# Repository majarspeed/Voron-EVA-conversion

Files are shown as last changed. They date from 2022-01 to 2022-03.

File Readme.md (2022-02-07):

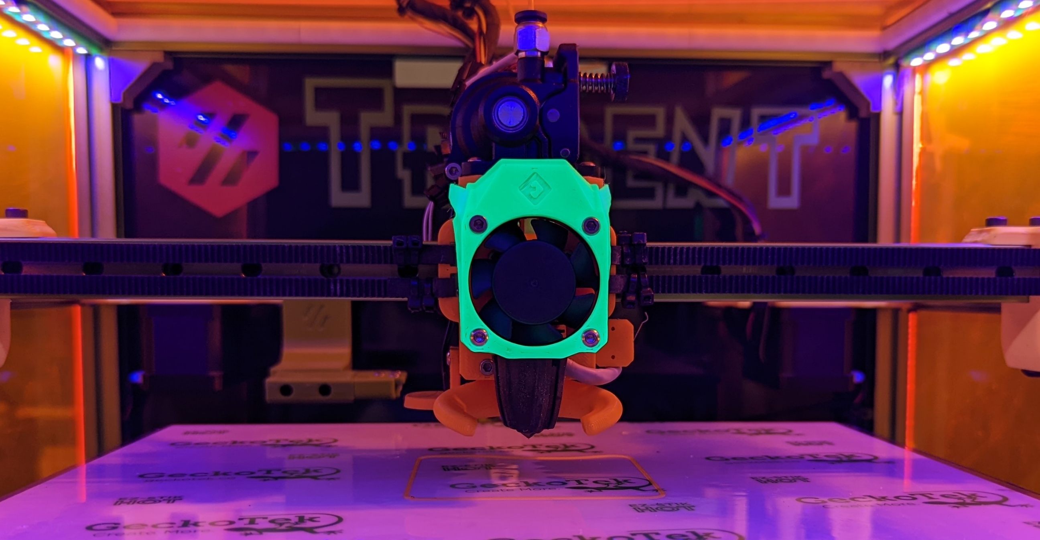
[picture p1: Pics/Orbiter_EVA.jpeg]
Orbiter EVA on Voron

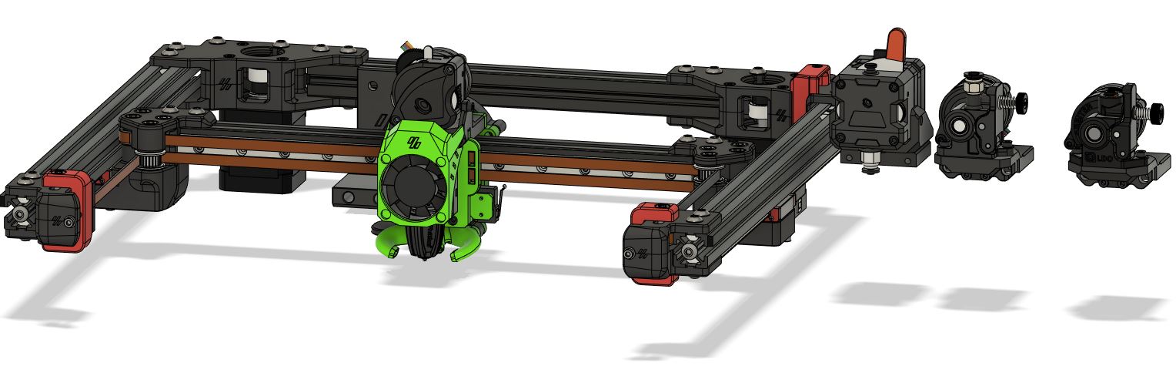
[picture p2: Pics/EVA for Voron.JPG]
fusion EVA on Voron


This is a repository for the CAD and STL for the EVA to Voron conversion. 

This is not an original work. All of this is the work of the EVA team and Voron Design. I only made minor modifications to allow the use of the excellent EVA hotend system. Please visit EVA at https://main.eva-3d.page/ and Voron Design https://vorondesign.com/ and consider suppoting both of these worthy projects. 

The goal was to make as little change to either system as possible. So primarily I wanted to not have to redesign the belt pathing on the Voron or relocate the rail. And to minimize the changes to the EVA and retain as much as I could of the EVA compatibility. 

Primarily what this means is I added heat sets to the top of some mounts and added a spacer/endstop with mounting holes for the faceplate to the MGN12. 
Homing does need to be modified to work with this modification. I am using Homing override to ensure that I home x and they move to a location away from the corner before I home the y axis.

# Update 2 

Added some addtional spacing on the housing. Some was just a little to close. 
Added ad spacer using a df2 microswitch. 
Added sherpa mini top. 

Began testing of a MGN 9 variant. 

Some have asked for a weight comparsion. Weighed a EVA with Sherpa top all parts except hotend and extruder. 124 grams 

# UPDATE 1 Voron EVA conversion gets better Klicky
I have created a klicky duct that is based off of Whooppingpochard from the Voron discords design. And adapted it to the trihorn ducts. This is a much easier method and allows the use of the stock klicky and auto z configuration. This makes this a much easier conversion overall. Will retain the previous instructions in the klicky readme if you would still prefer to use this with that configuration. 

Also adding a user mod for some user based alternative parts. 
Adding a clamp style multipart uface desigh thanks to DoubleT ont he Voron Discord. 

# READ FIRST: THIS IS A CHALLENGING MOD. 
*"This mod may require significant individualization. Evaluate your own build and select your parts as needed." --Corvidbuild V2
This is an excellent description.*

I have a mix of modified parts and unmodified parts. 
Primarily you will need the modified Universal face and modified corexy back. The modified face has 4 holes to mount to the mgn 12 and 2 holes for heat sets to mount the hotend adapters. The modified universal plate should work with all popular hot end mounts these are un-modified (please visit the EVA site to get the files mount to fit your particular hot end.)I initially had the belts clamped with the mgn12 while effective you need 5 arms to get it lined up correctly. So I have added loops and secure the belts with zip ties.

The bottom is modified with heat sets for custom side mounted klicky mount if wanted.

The tops for several extruders are modified to work with this. LGX and LGX lite modified top as well as Orbiter 1.5/2.0 modified top and BMG modified top are included in the files. 

The x end stop is located on the carriage and is integrated with a new part I created called universal spacer.

I have a thinner versions of the rear universal wire mount.

All screw sizes are the same as stock with the exception of the through screws which need at least 5 extra mm to reach.

## THIS IS A CHALLENGING conversion please do not take this lightly.

# Configuration Changes

## Homing 
Below is an example of my homing changes to ensure I do not hit the AB motor mounts. 

```
[homing_override]
axes: z
set_position_z: 0
gcode:
   G90
   G0 Z5 F600
   G28 X
   ## Set X below to a sale location off of the right corner to ensure that you do not hit the AB mount when HOMING. 
   G0 X225 F7200
   G28 Y
   ##	XY Location of the Z Endstop Switch
   ##	Update X0 and Y0 to your values (such as X157, Y305) after going through
   ##	Z Endstop Pin Location Definition step.
   G0 X163.00 Y295 F3600 
   G28 Z
   G0 Z10 F1800
   ##Park after Homing
   G0 X163 Y260 Z30 F7200 
   ```

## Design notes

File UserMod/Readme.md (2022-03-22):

Added alternative klicky mount for Volcano/UFH nozzles. 
Added Orbiter 2.0 Hartk mount 
Addied Umbilical mount for frame.

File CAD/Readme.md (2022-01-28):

Location for all CAD for the EVA conversion.

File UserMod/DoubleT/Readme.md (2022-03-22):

Multipart Universal face for Voron EVA conversion. Contributed by DoubleT from the Voron Discord. 

3/22/22 
Added alternative klicky mount for Volcano/UFH nozzles.
Added Orbiter 2.0 Hartk mount 
Addied Umbilical mount for frame.

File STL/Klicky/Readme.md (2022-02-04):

The new duct based mount is a simpler and easier to implement solution. You just need to print the slightly longer arm mount or use the variable height arm from the Klicky mod repo. And fllow the standard setup for klicky mod. 

I also added a thicker klicky side mount and moved the directions for this here in case you still wish to utilize it. 

# Side mount Klicky needed changes.
## Probe

### Probe offset 
```
x_offset: -24
y_offset: 30
```
### Mesh max 
Needs to be shrunk as it looks at the nozzle location not the offset. 
```
mesh_max: 250,260 
```
## Z-tilt
And the Z-tilt will need to be adjusted for your particular bed. My bed is not a standard so would not be helpful. Just keep in mind that the probe offset is not used when setting these. 
# Auto-z
This I am looking to improve 
But currently this is the changes I used to make this work in my configuration. 
These are the ADDTIONAL besides the normal changes to configure auto z. 
The below are found in the klicky-probe-for_VT.cfg on my configuration. 
### Probe Entry 
The below needs to be modified to change where it starts the dock and undock from. 

```
# Probe entry location
        #set the below location to 20 mm to the right of the dock location. 
         G0 X 143 Y 275 F3600
        #G0 X{Dx|int - Ax|int} Y{Dy|int - Ay|int} F{St}
        #{% if Dz != -128 %}
        #    G0 Z{Dz|int - Az|int} F{Sd}
        #{% endif %}
```

### Dock move
Below needs to be added:
```
#dock move
Variable_dockmove_x:             0
Variable_dockmove_y:           -40
Variable_dockmove_z:             0

#attach move
Variable_attachmove_x:         -40
Variable_attachmove_y:           0
Variable_attachmove_z:           0
```

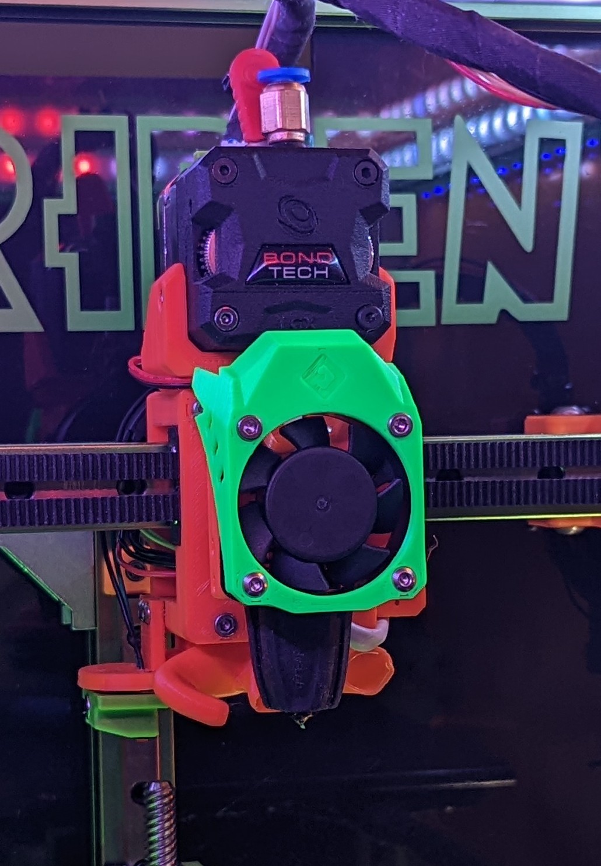
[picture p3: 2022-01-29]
Pics/LGX_EVA.jpeg

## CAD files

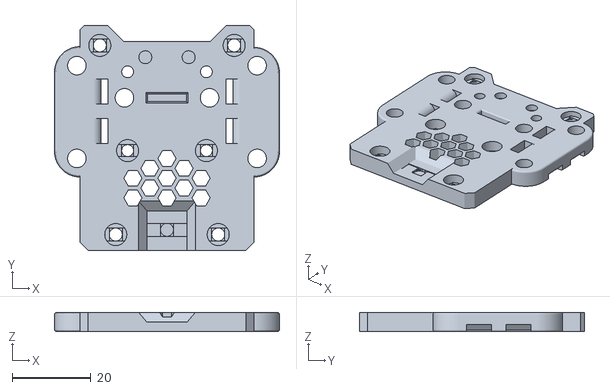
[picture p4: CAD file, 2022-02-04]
UserMod/DoubleT/Voron_U-face_mpart_main.stl
57.1 x 57.0 x 4.90

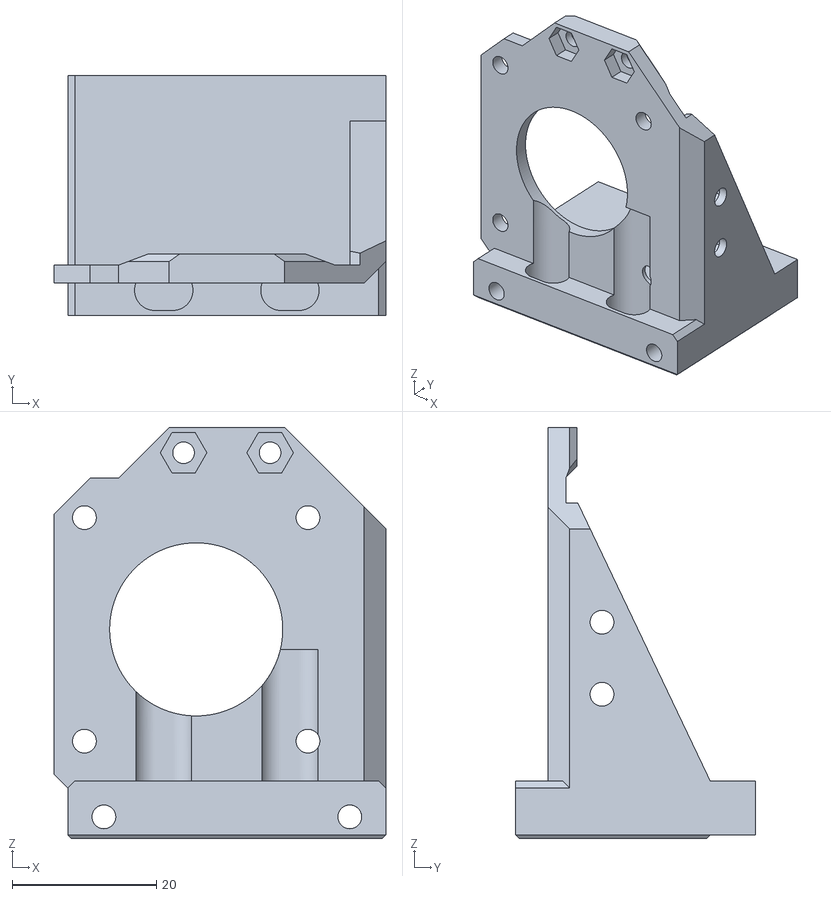
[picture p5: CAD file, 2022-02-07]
STL/BMG/top_bmg_mgn12.stl
46.0 x 33.3 x 57.0

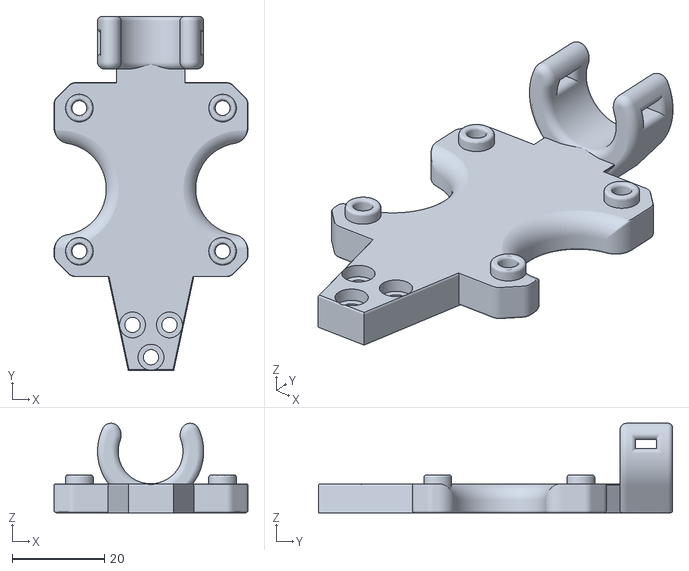
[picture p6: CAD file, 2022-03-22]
STL/huvud_eva_oriented.stl
42.0 x 76.7 x 19.4

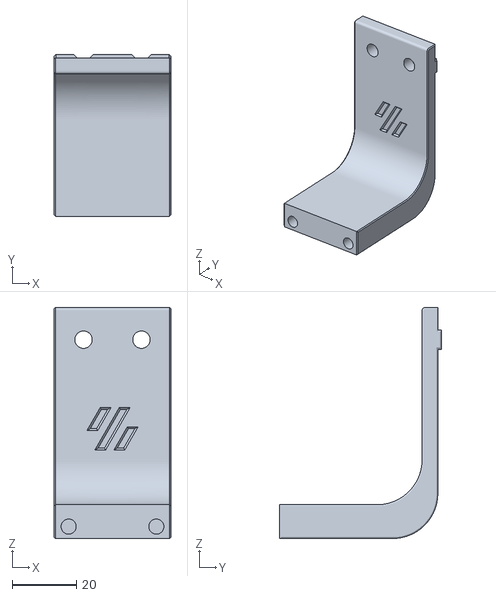
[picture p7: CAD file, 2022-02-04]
STL/Klicky/Duct height arm EVA.stl
36.3 x 50.3 x 71.8

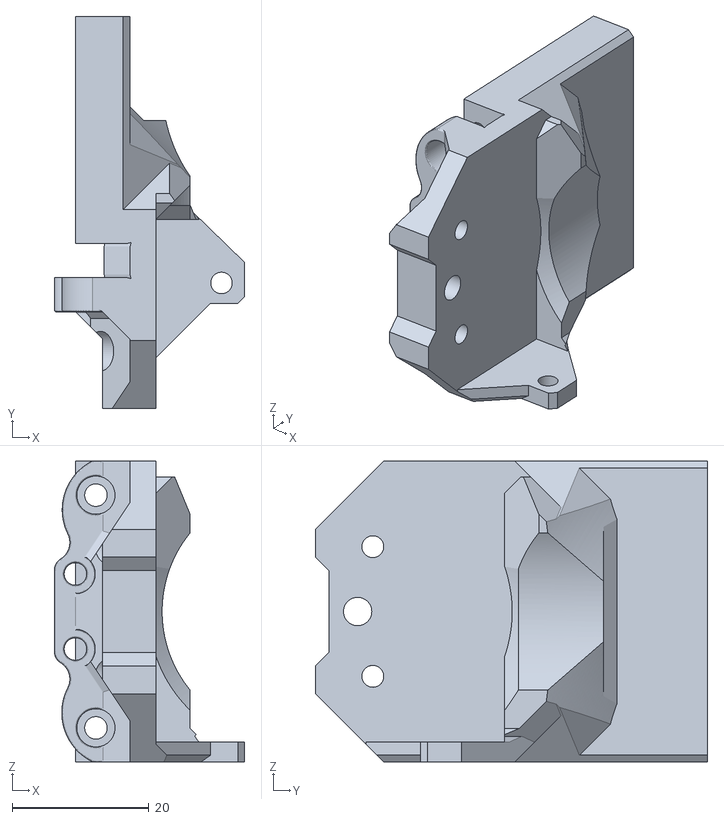
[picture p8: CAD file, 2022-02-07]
STL/LGX/top_mgn12_LGXM.stl
27.9 x 57.5 x 44.1

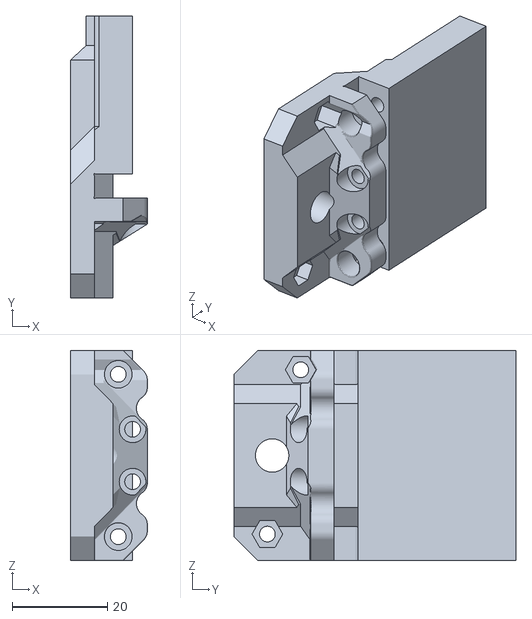
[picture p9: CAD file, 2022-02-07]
STL/orbiter/top_orbiter_1_5_mgn12.stl
16.1 x 59.2 x 44.1

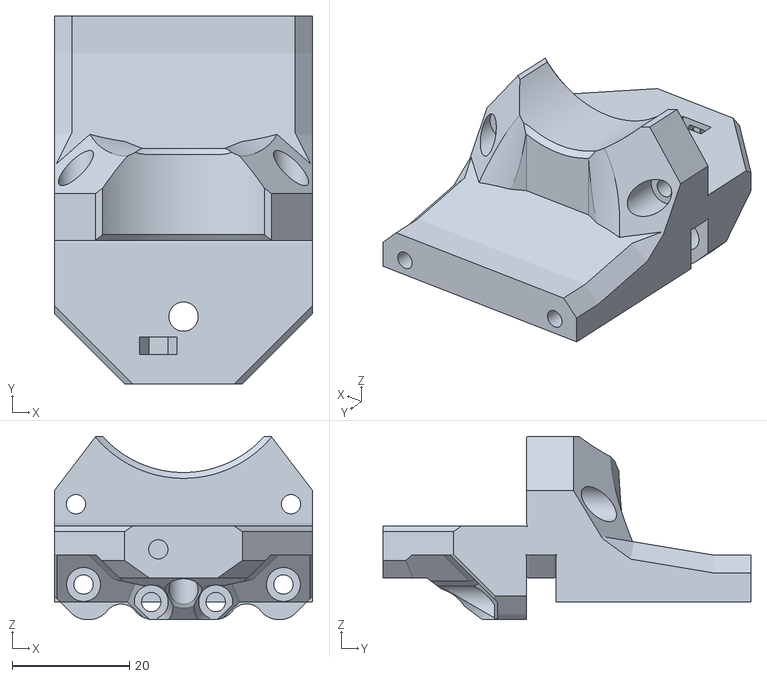
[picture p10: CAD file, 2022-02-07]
STL/Sherpa/top_sherpa_mgn12.stl
44.1 x 62.8 x 31.3

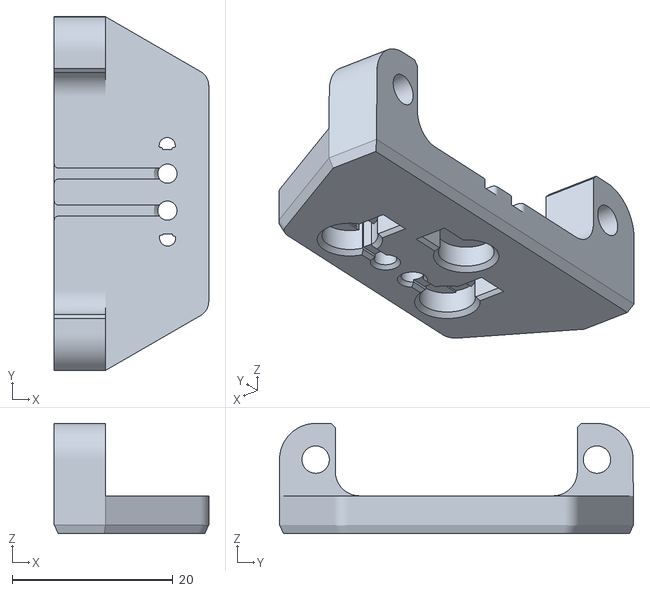
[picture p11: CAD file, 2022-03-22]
UserMod/DoubleT/Eva Mount dt klicky mount.stl
19.2 x 44.0 x 13.7

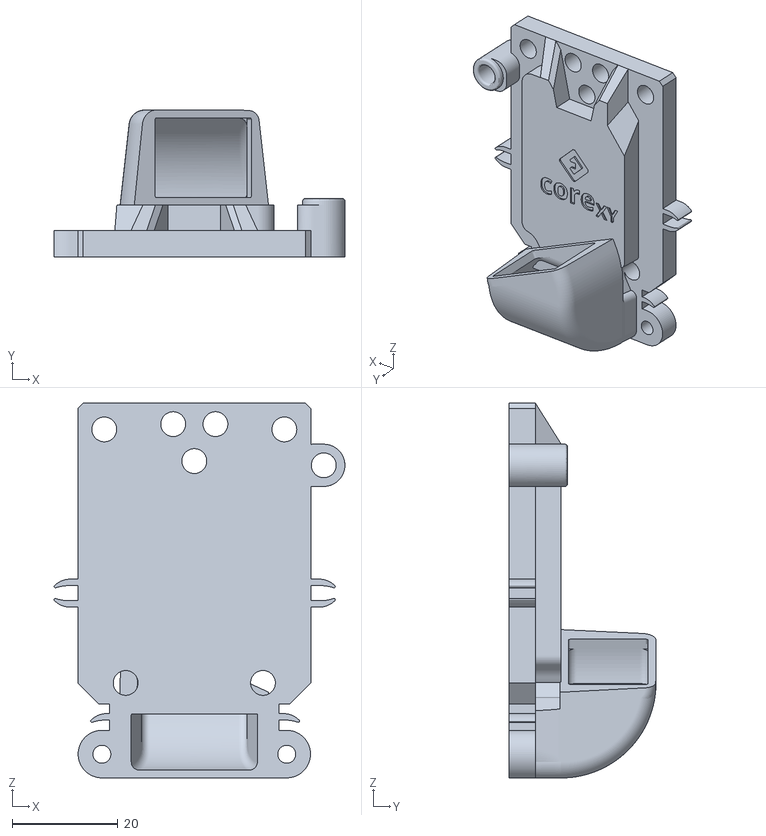
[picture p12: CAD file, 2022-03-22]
STL/Corexy_short_backw.stl
55.1 x 27.9 x 71.0

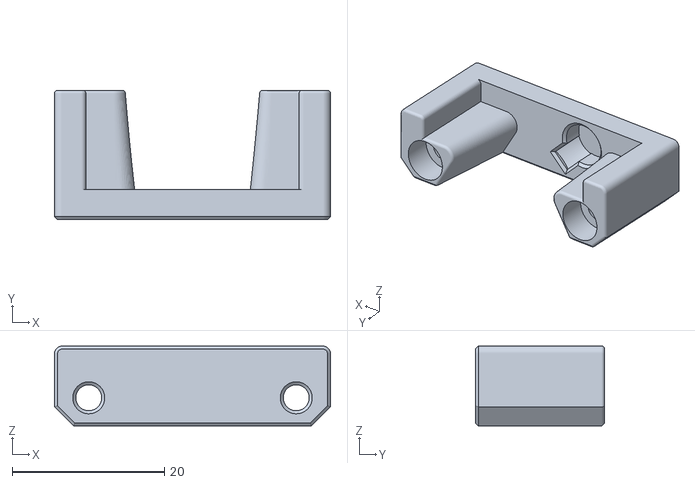
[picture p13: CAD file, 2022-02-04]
STL/Klicky/Probe Dock v2.stl
36.3 x 17.0 x 10.5

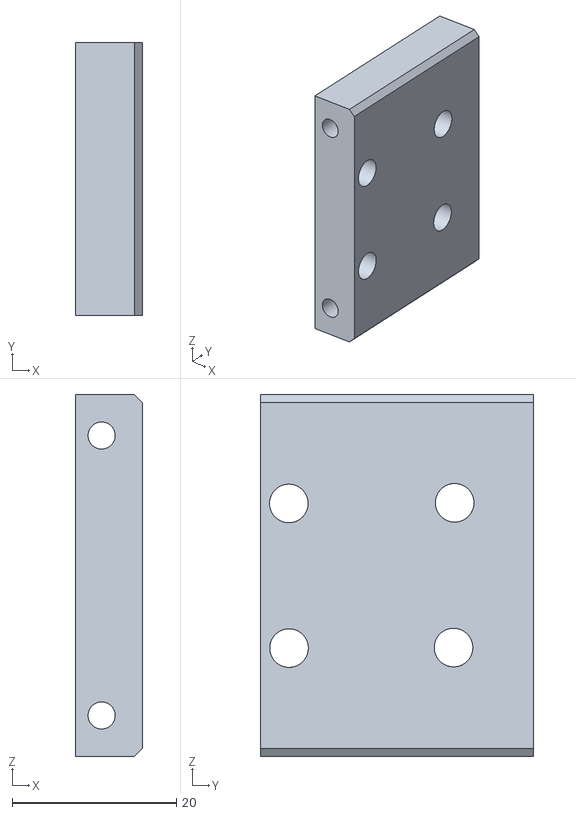
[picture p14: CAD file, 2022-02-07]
STL/LGX/top_lgx_mgn12.stl
8.20 x 33.3 x 44.1

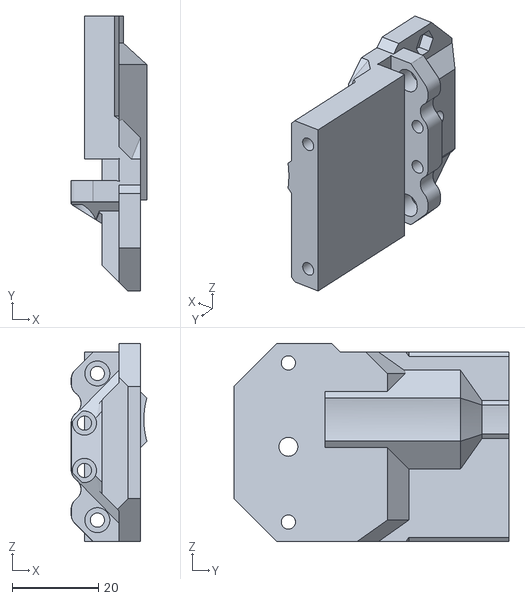
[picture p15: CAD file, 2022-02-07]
STL/orbiter/top_orbiter_2_0_mgn12.stl
17.6 x 63.9 x 46.1

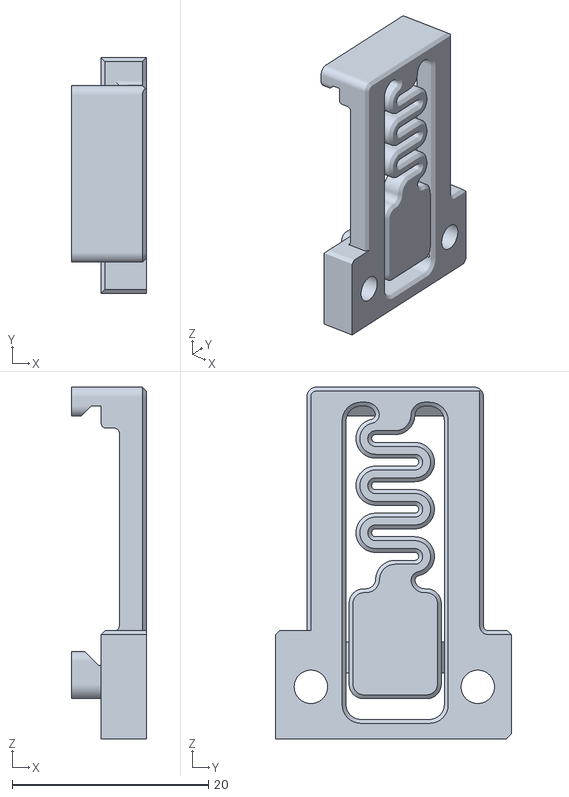
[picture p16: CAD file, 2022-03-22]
UserMod/DoubleT/PCB Bracket - 20mm.stl
7.60 x 24.0 x 35.8

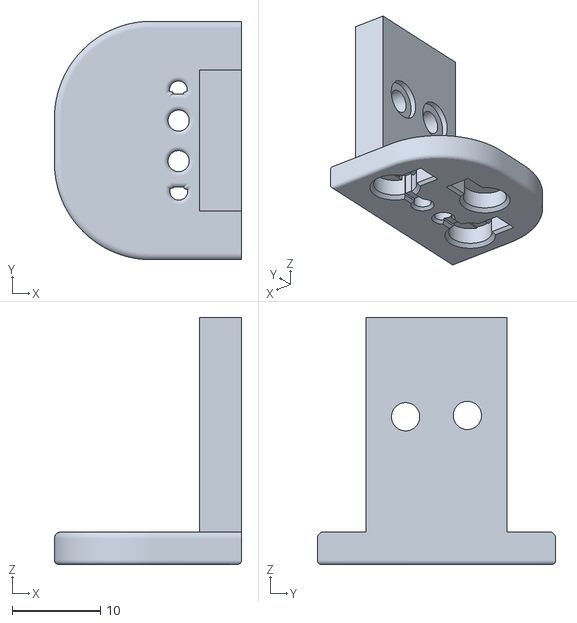
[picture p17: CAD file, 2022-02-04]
STL/Klicky/EVA klicky Mount thicker.stl
21.2 x 27.0 x 28.0

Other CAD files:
STL/LGX/VCv1_top_lgx_mount.stl
STL/U face Voron part.stl
UserMod/DoubleT/Orbiter 2.0 backplate.stl
STL/Klicky/Dock Sidemount fixed v2.stl
CAD/EVA Voron conversion alternative parts.f3d
STL/Klicky/Klick side mount adapter.stl
STL/Universal Spacer.stl
STL/VCv1_Corexy_short_back.stl
STL/VCv1_bottom_mgn12_short_duct.stl
STL/VCv1_cable_holder.stl
STL/VCv1_unversal_cable_mount.stl
STL/shroud.stl
UserMod/DoubleT/Belt Clamp.stl
UserMod/DoubleT/Voron_U-face_mpart_he-block.stl
UserMod/DoubleT/cable_holder_v1 v1.stl

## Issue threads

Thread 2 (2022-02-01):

Klicky probe mount can be cracked if over tightened.

majarspeed, 2022-02-01:
New klicky dock needs to be designed or modified.

majarspeed, 2022-02-04:
Both a thicker Klicky mount for side is now available and a duct based mount are now available.

Closed 2022-02-04.

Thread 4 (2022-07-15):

stl not complete

kaisarantonn, 2022-07-15:
need for hotend mount, the stl are not available in this project file
 when i refer to eva web page, the hotend mount is looking different from your cad file,
i want to use rapido for my 2.4 and dragon for my trident. which version of eva this refers to?

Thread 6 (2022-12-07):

Voron 2.4 gantry back space

sat3d, 2022-12-07:
Hi man! first of all, what a great job! Would like to know if any mod is needed in terms the EVA use a back fan that seems to not fit with gantry space at the back of the X extrusion, I have a 2.4 and can not see how can it fits.

Thanks!

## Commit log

2022-02-04 The better klicky update.
    Added a better side mount klicky mount. Added a duct based klicky mount.
    [EVA Voron conversion alternative parts.f3d]
2022-02-04 Better klicky updated
    Added thicker klicky side mount. added duct mount klicky and arm for the new height.
    [Duct height arm EVA.stl, EVA klicky Mount thicker.stl, Probe Dock v2.stl]
2022-02-09 Add files via upload
    Uploaded correct STL
    [U face Voron part.stl]
2022-03-22 Add files via upload
    Added QOL upgrades back, Triduct with additional wiring help. Added a mount for huvud board.
    [Corexy_short_backw.stl, huvud_eva.stl]
2022-03-22 A umbilical mount created by Double T
    [cable_holder_v1 v1.stl]
2022-03-22 Add files via upload
    Alt Klicky mount. Orbiter 2.0 hartk mount and Umbilical thanks to Double T.
    [Eva Mount dt klicky mount.stl, Orbiter 2.0 backplate.stl, PCB Bracket - 20mm.stl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]
2022-03-22 Add files via upload
    Added obiter Hartk mount, Alt Klicky duct for Volcano or UHF, And Umbilical mounts.
    [Eva Mount dt klicky mount.stl, Orbiter 2.0 backplate.stl, PCB Bracket - 20mm.stl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]
